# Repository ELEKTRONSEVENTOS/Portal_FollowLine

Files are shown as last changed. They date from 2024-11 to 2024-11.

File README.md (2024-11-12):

# Portal_FollowLine
Esse é um portal de tomada de tempo para competições de robótica para a categoria FollowLine

Foi utilizado dois sensores E18-D80NK para detectar a passagem do robô no portal, o potenciomentro fica de fácil acesso.

Os cabos utilizados form do tipo manga de 4 vias + GND (Malha)
Um cabo com 1,20m com ambos os lados com conector MIC FEMEA de 4 vias em ambos os lados, conectando 1 com 1, 2 com 2, 3 com 3 e 4 com 4.
O outro cabo com comprimento de 3 m também com conector MIC FEMEA de 5 vias em ambos os lados e conectados como o anterior.

No suporte do sensor (Parede_Sensor.stl) foram instalados dois conectores MIC, um MIC Femea de 5 vias e outro MIC Femea de 4 vias e estes 
foram conectados entre si seguindo a orientação do arquivo (Diagrama dos Conectores.png).
Como cada suporte pega apenas um sensor, escolha um suporte para ser o sensor 1 e outro será o sensor 2. Observe que no Diagrama do Portal os conectores MIC de 4 vias ficam em posições opostas, 
assim, o cabo manga de 4 vias conecta um portal ao outro e sem cruzamento de cabos. O cabo de MIC de 5 vias conectará apenas um dos lados do portal ao sistema que cronometrará os tempos.

Os arquivos Parede_Sensor.stl e Parede_Simples.stl foram impressos sem suporte e em PLA. Os pés tem entrada para ventosas para ajudar a fixar na pista.

A parte superior do portal (Chegada e Largada) tem a opção de impressão bi-partida ou não. No caso da bi-partida, esta foi impressa em pé em relação a base e foi colocado suporte com "roof top" para que as
letras podessem ter uma boa definição. Para cada parte superior imprimir uma emenda_inferior e duas emenda_superior.

Caso queira colocar LED's luminosos, os arquivos AcrilicoX.dxf já possui as dimensões necessárias. O acrilico de 10mm de espessura deve ser contado a laser e na parte das letras usar a opção scan na máquina
de corte a laser.

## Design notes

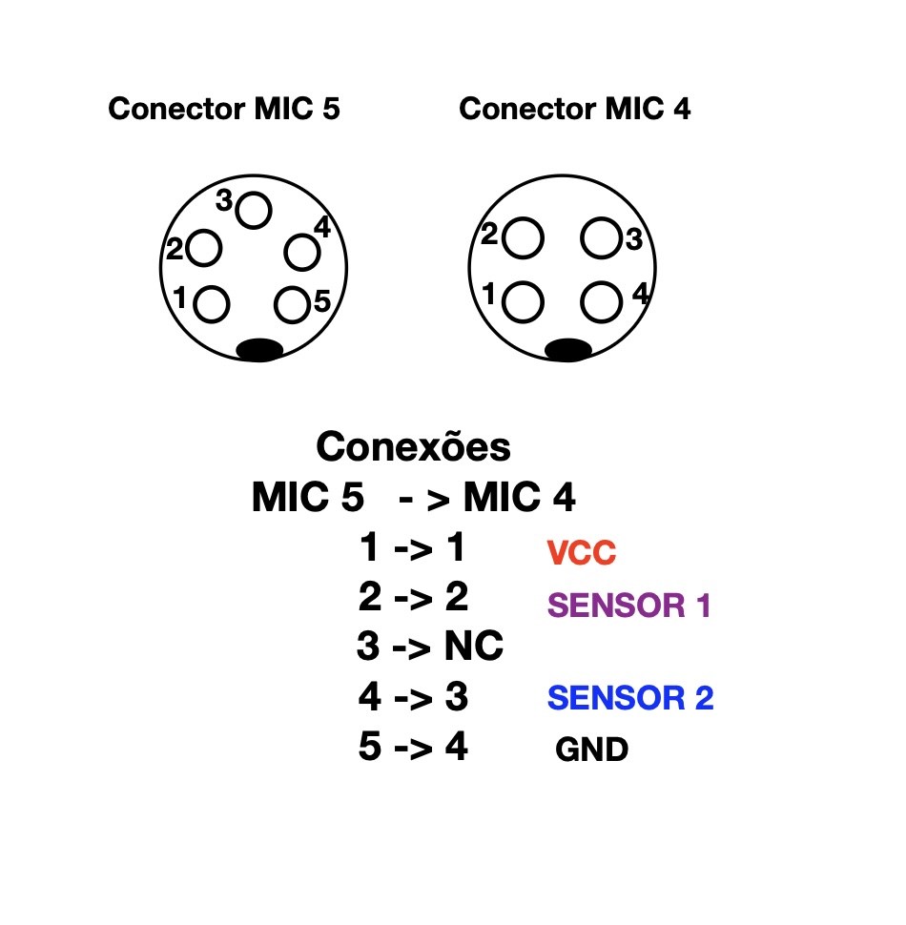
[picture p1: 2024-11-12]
Diagrama dos Conectores.jpg

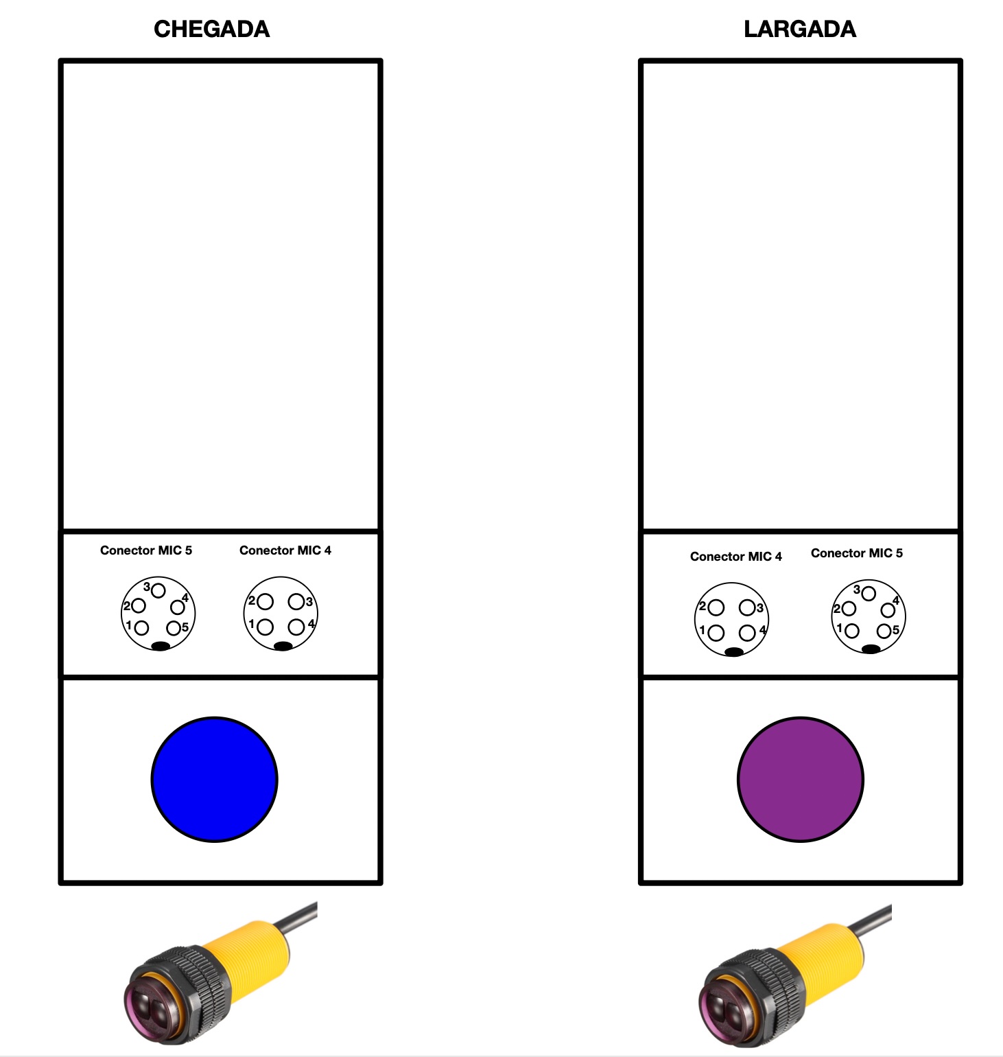
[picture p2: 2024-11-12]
Diagrama do portal.jpg

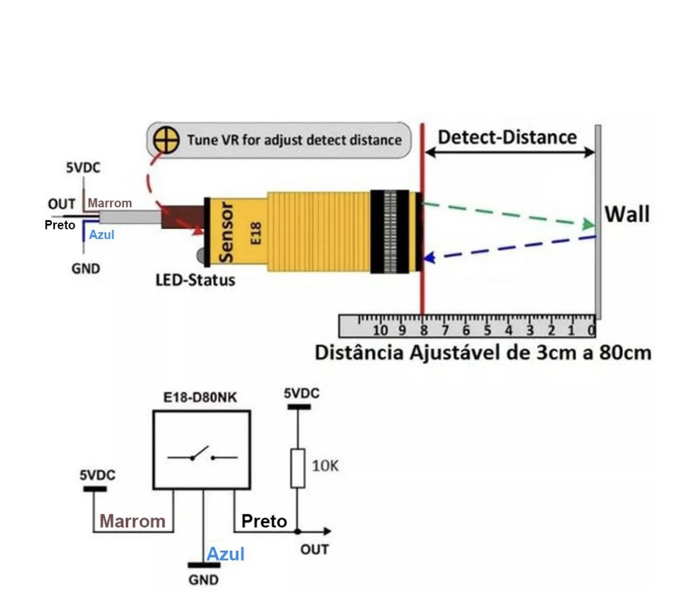
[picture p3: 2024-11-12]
Sensor E18-D80NK.jpg

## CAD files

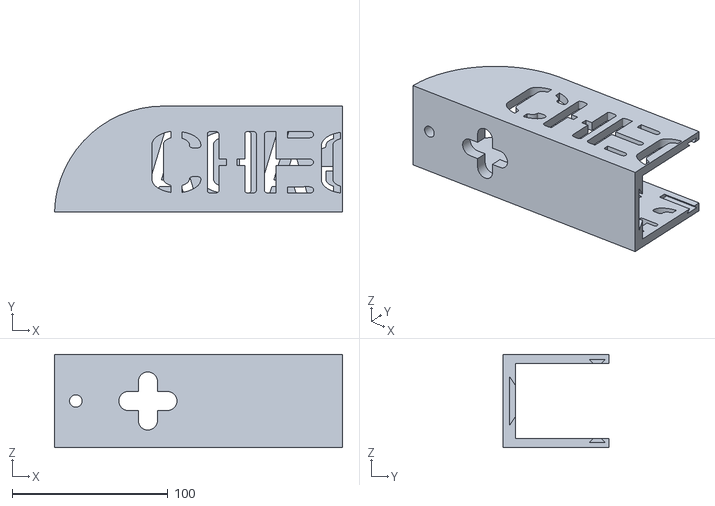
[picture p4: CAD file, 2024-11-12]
Base_ChegadaA.STL
185.0 x 68.0 x 60.0

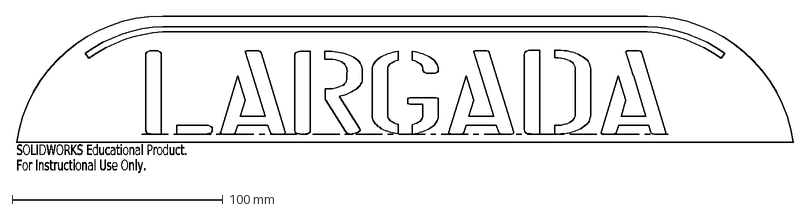
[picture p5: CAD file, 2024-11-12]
AcrilicoLargada.DXF
SOLIDWORKS Educational Product.
For Instructional Use Only.

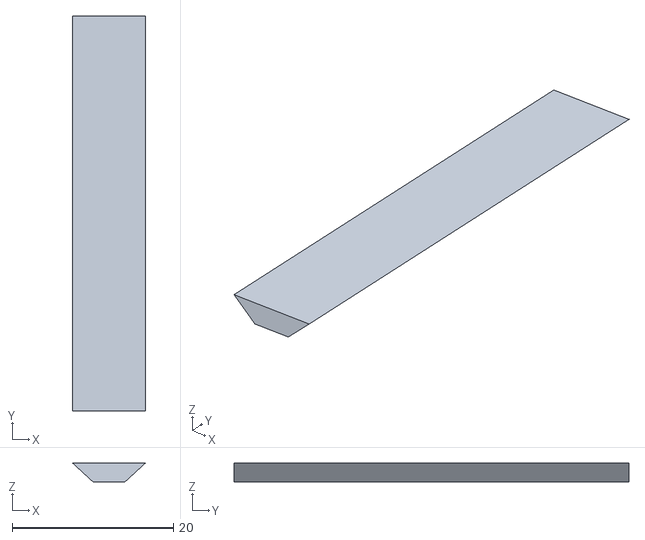
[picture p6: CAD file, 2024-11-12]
emenda_superior.STL
9.00 x 49.0 x 2.30

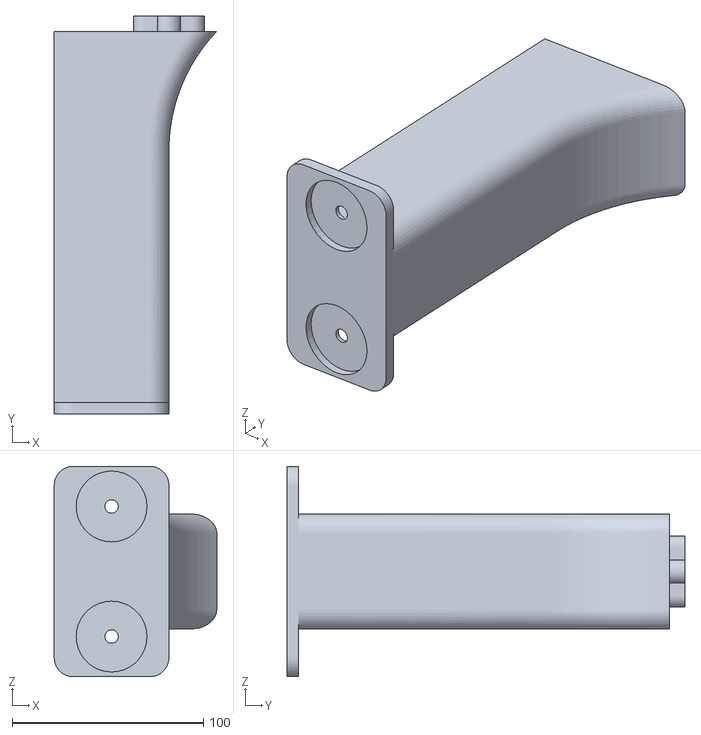
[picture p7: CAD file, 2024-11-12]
Parede_Simples.STL
85.0 x 208.0 x 110.0

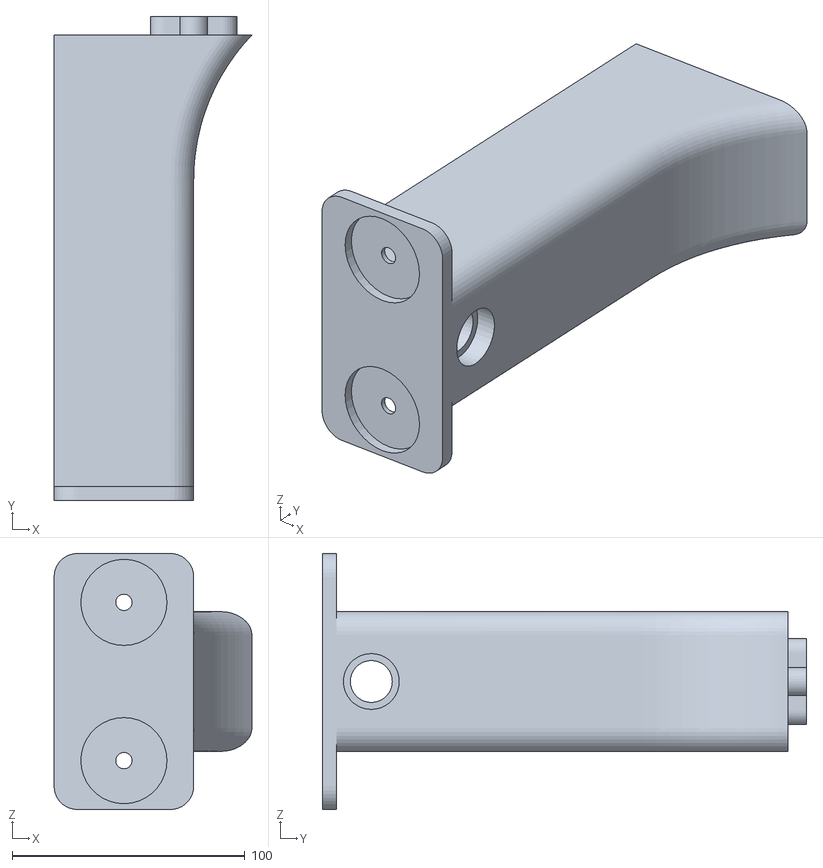
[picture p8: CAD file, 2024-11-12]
Parede_Sensor.STL
85.0 x 208.0 x 110.0

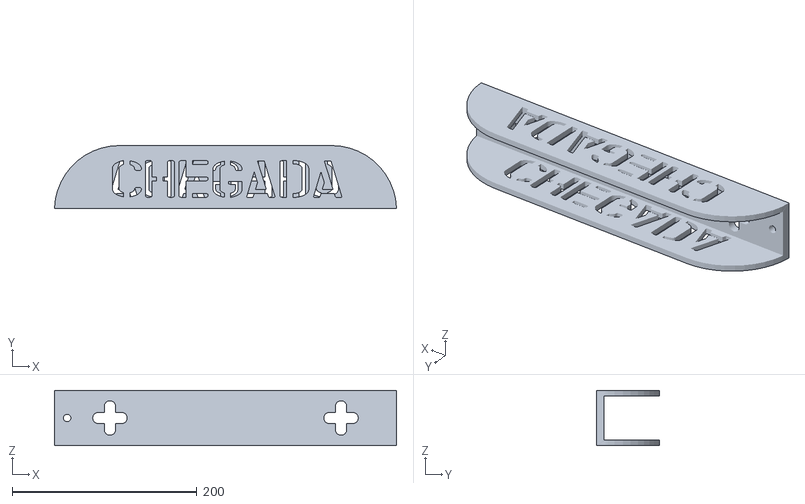
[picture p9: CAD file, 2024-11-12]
Base_Chegada.STL
370.0 x 68.0 x 60.0

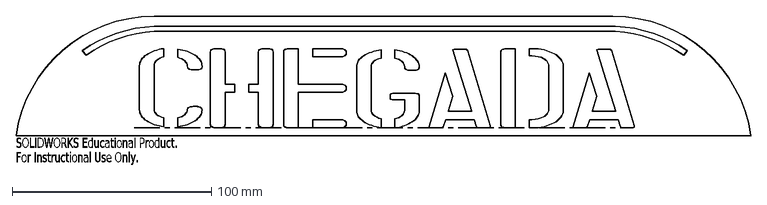
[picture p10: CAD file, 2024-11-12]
AcrilicoChegada.DXF
SOLIDWORKS Educational Product.
For Instructional Use Only.

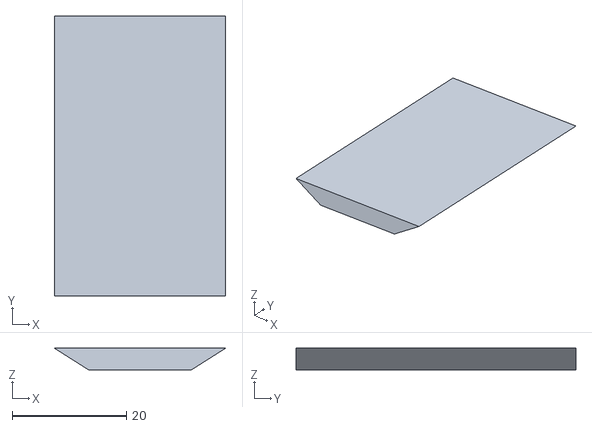
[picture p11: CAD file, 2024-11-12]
emenda_inferior.STL
30.0 x 49.0 x 3.80

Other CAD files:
Base_ChegadaB.STL
LargadaA.STL
LargadaB.STL
